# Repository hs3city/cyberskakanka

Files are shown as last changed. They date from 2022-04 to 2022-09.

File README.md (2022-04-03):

# cyberskakanka

## Wiring the Stuff Together

### Connecting Arduino and Weight Sensors

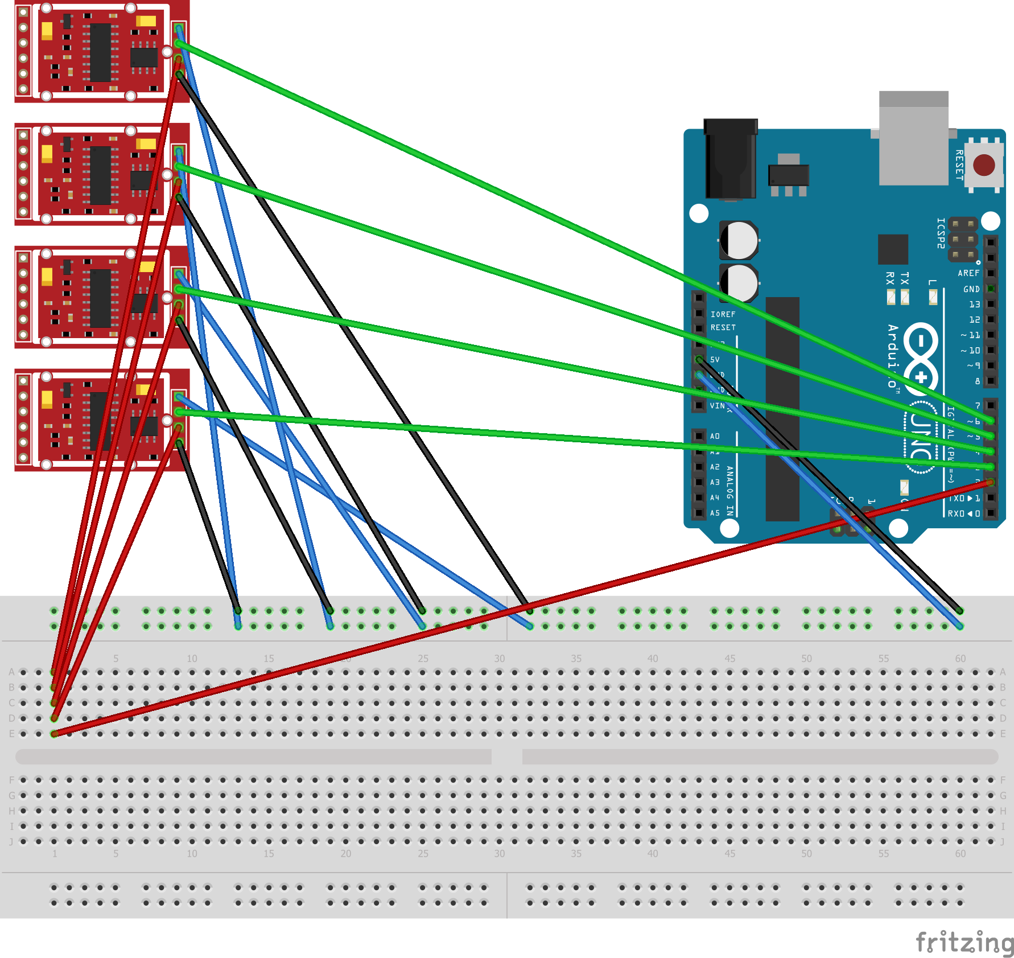
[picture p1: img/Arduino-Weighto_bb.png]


### Connecting Arduino and Raspberry Pi via I2C

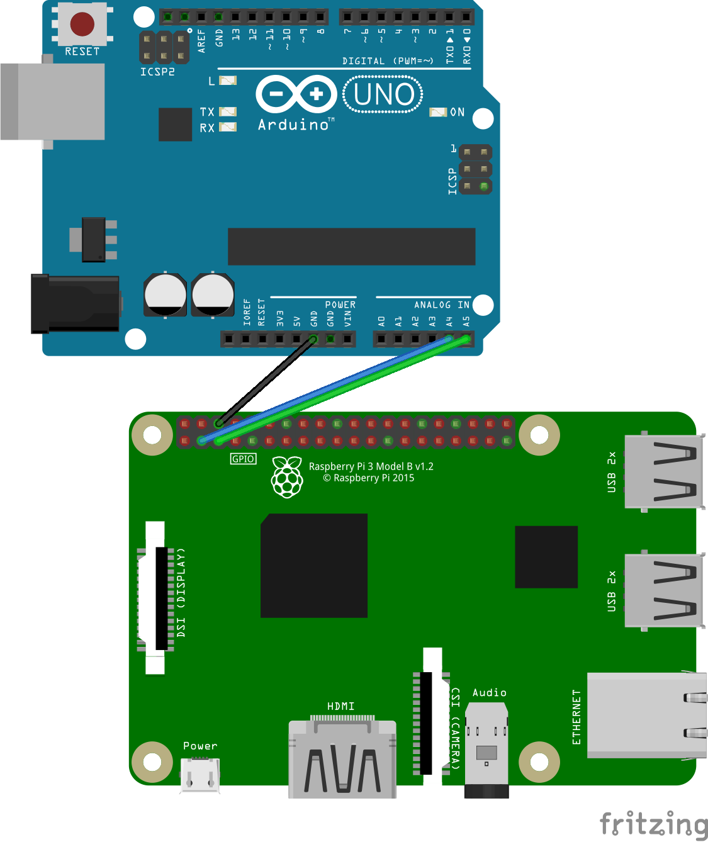
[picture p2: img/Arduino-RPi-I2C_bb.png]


### Connecting Raspberry Pi with WS212B LED Strip

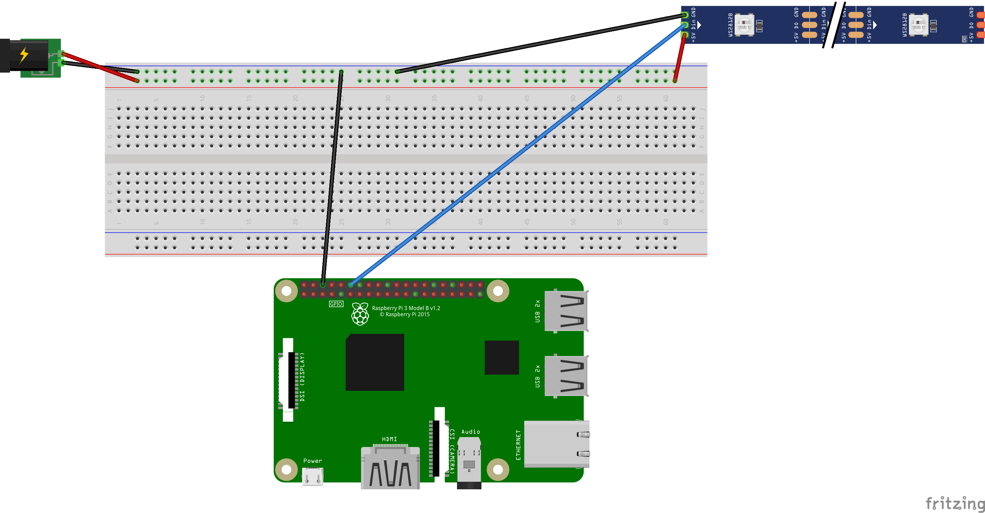
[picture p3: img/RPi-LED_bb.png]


## The Hardware

### The Base

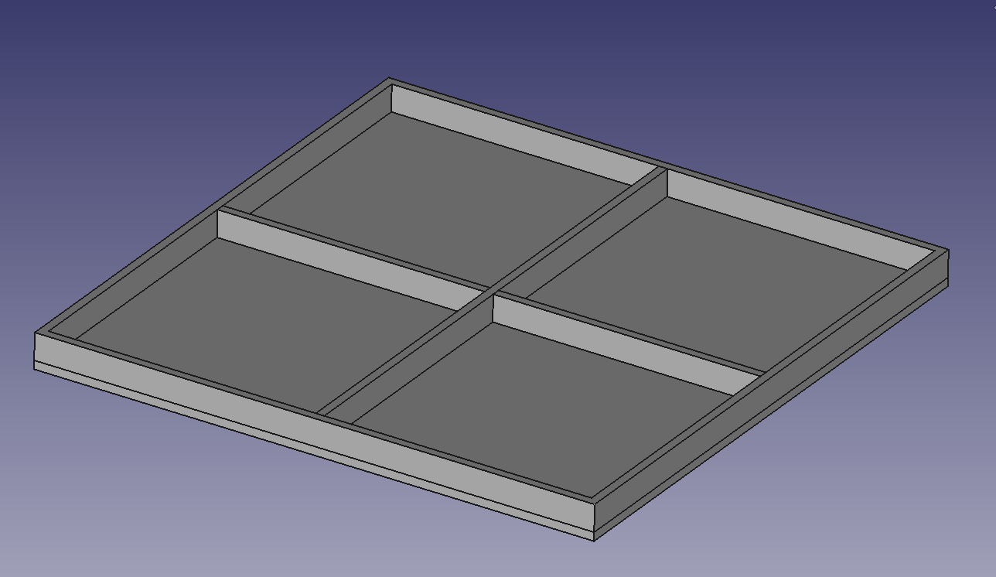
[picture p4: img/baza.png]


### The Base with Two Tiles Fit

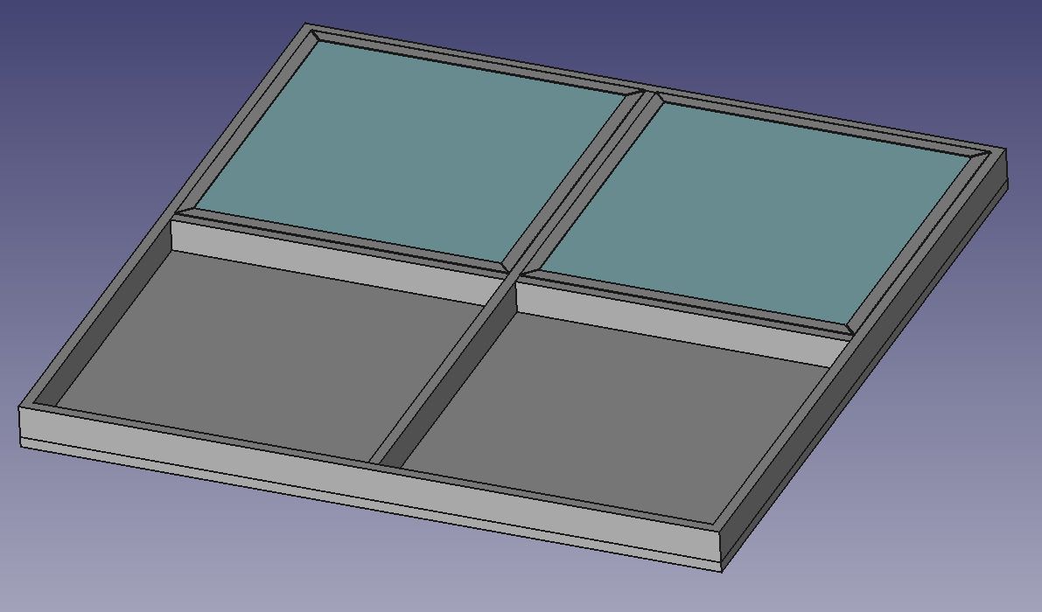
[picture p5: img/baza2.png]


### The Tile

- 16mm MDF on the bottom
- a layer of white cardboard
- 5mm transparent plexi

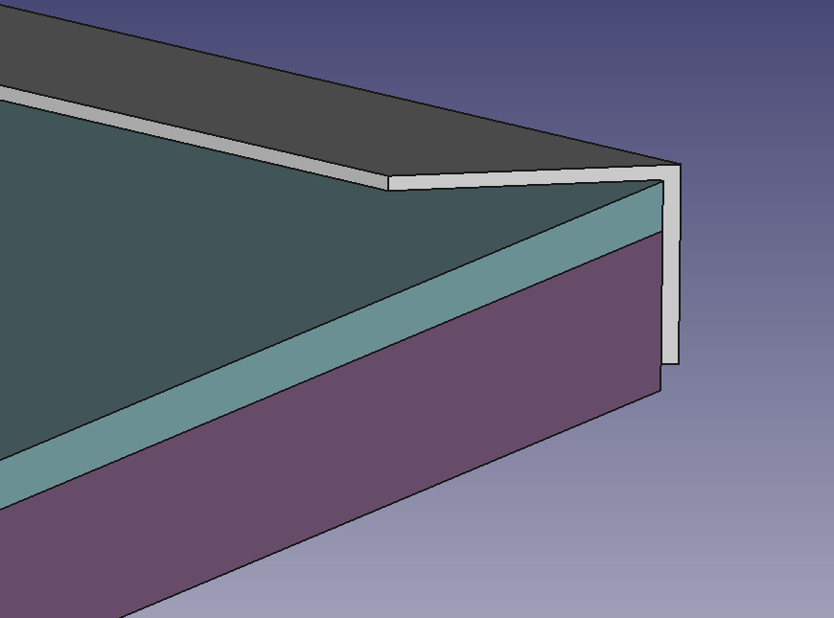
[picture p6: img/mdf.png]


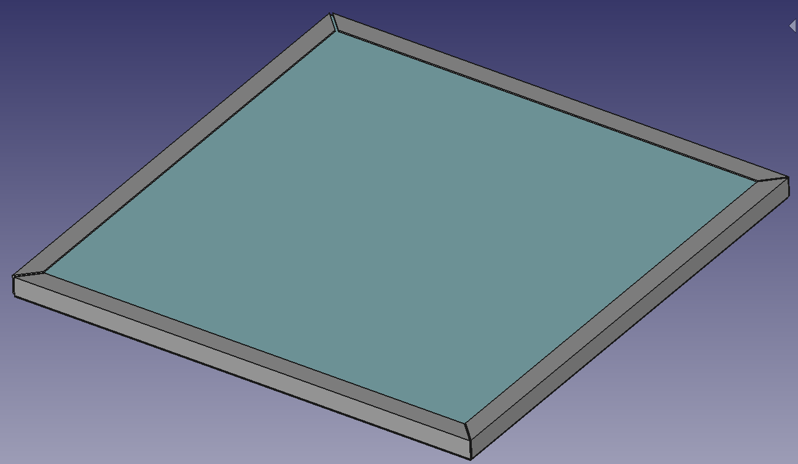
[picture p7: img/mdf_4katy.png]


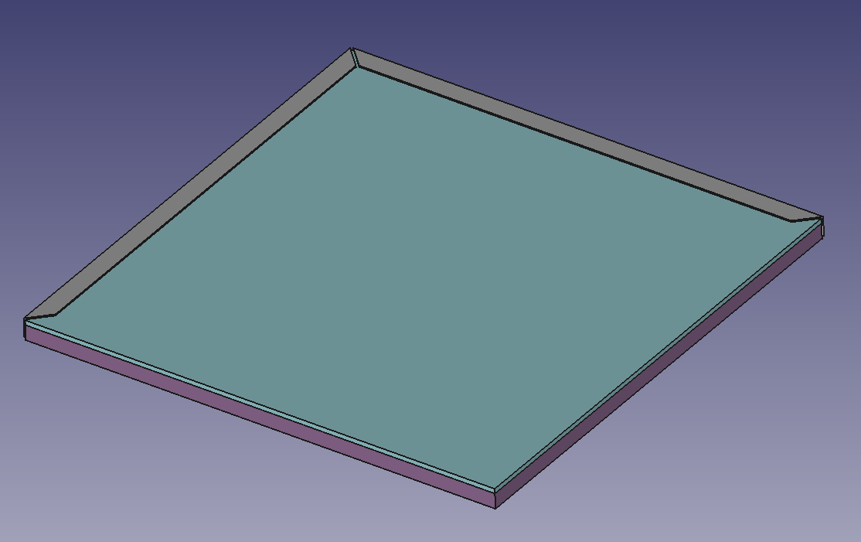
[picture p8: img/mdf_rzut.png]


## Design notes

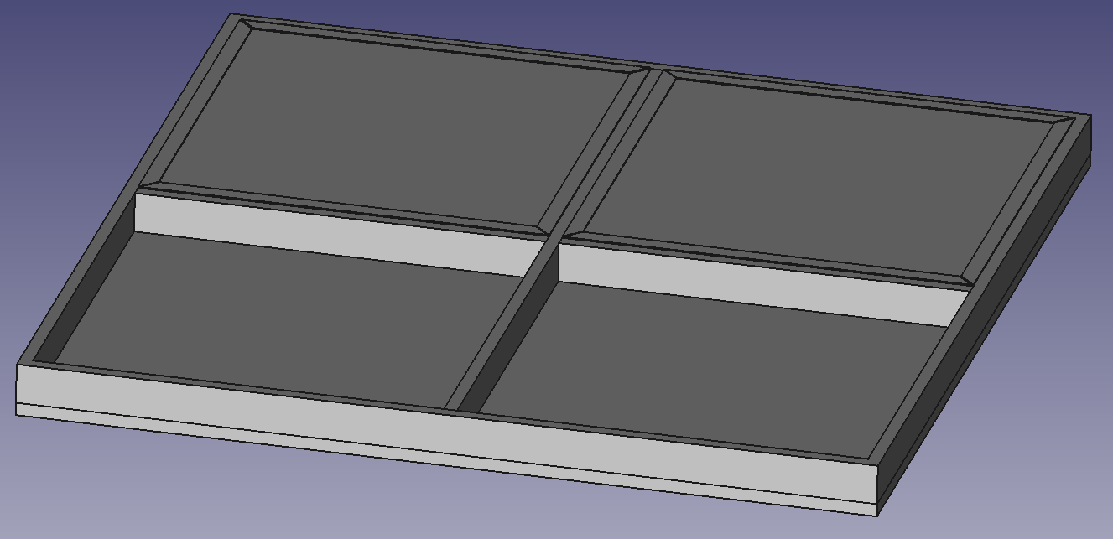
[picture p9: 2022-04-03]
img/cyberskakanka.png

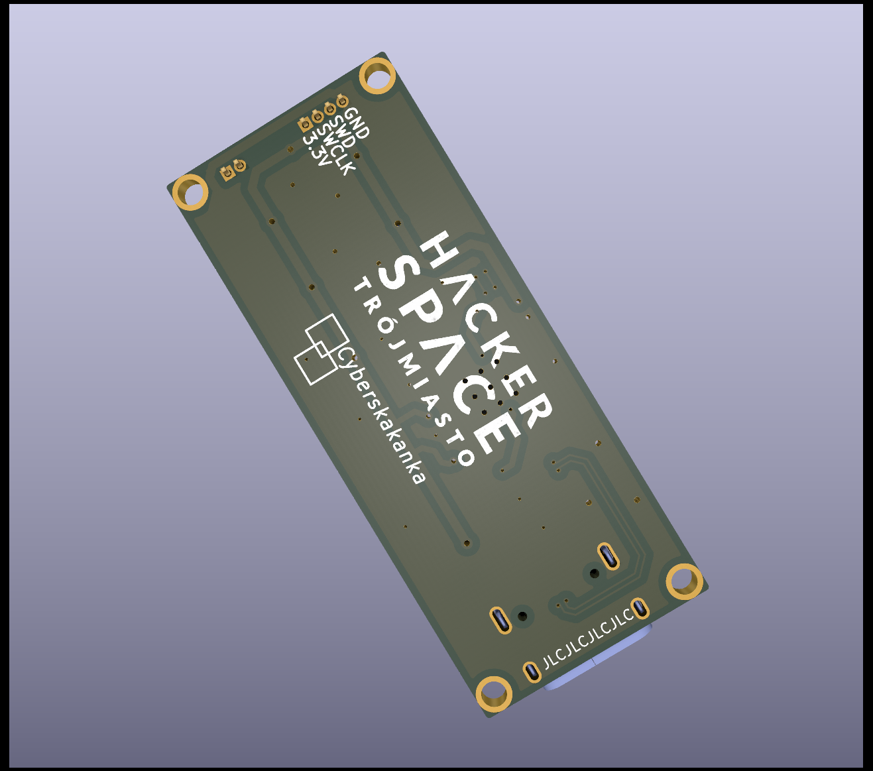
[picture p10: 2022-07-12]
hs3-arduino-nano/export/hs3-arduino-nano-bottom.png

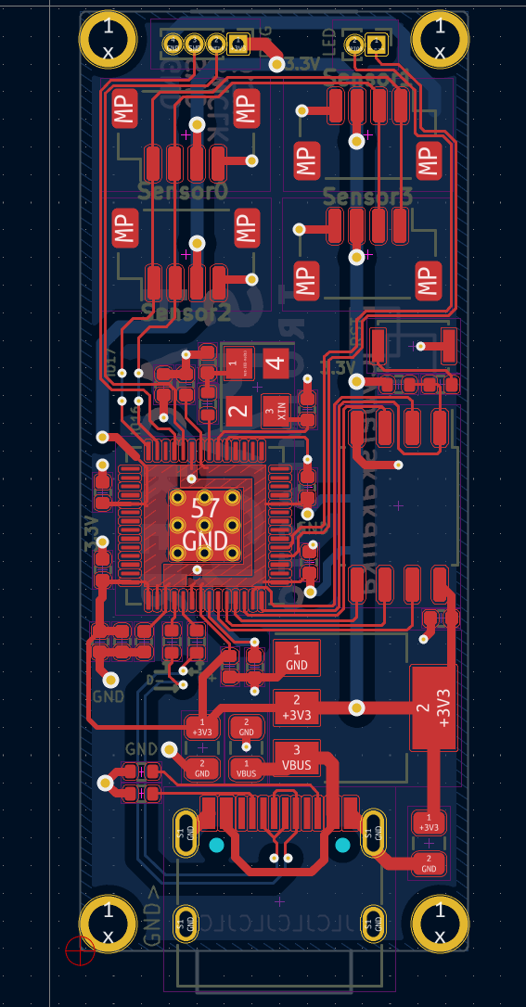
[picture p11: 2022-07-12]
hs3-arduino-nano/export/pcb.png

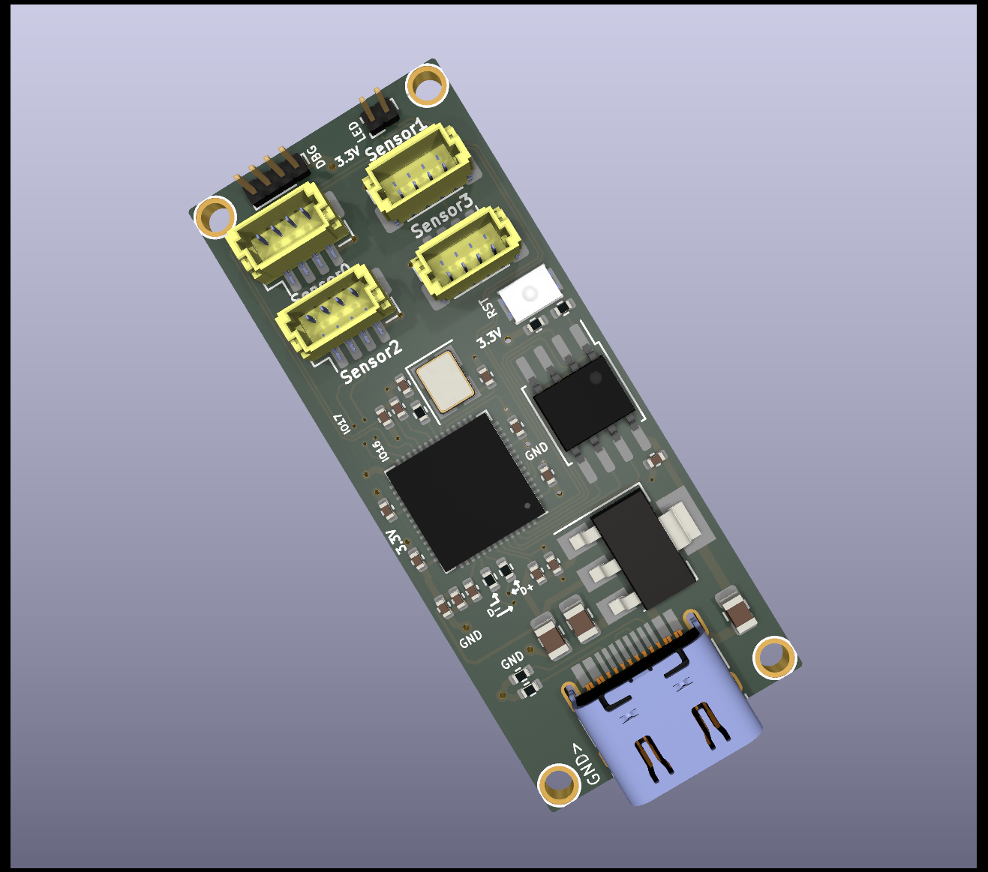
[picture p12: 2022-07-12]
hs3-arduino-nano/export/hs3-arduino-nano-top.png

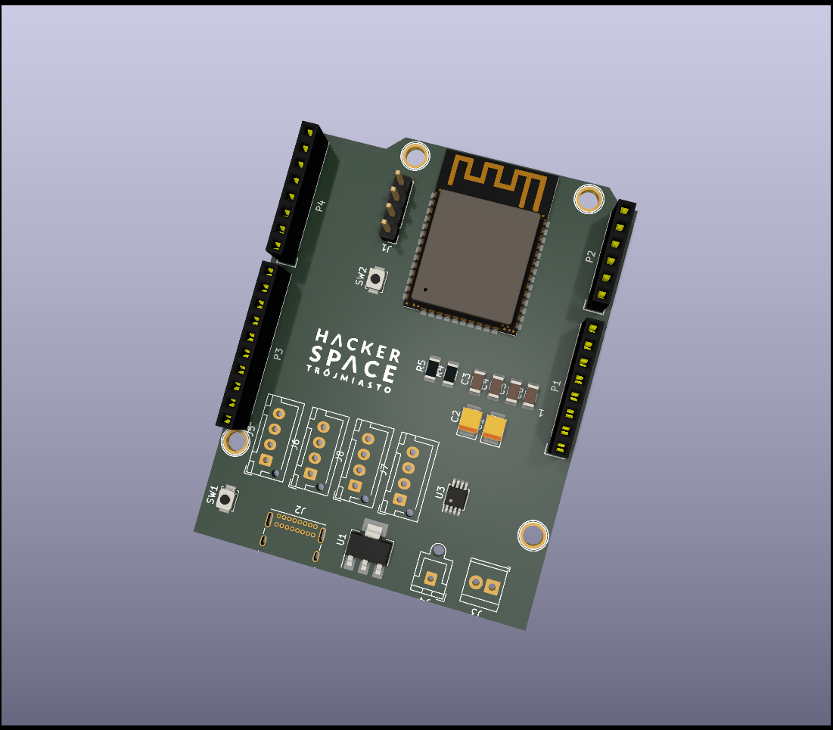
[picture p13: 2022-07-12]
hs3-arduino/hs3-arduino-render.png

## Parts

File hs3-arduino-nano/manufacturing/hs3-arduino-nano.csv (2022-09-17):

Comment | Designator | Footprint | LCSC
27p | C1,C2 | Capacitor_SMD:C_0402_1005Metric | C1557
10u | C3,C5,C6 | Capacitor_SMD:C_0805_2012Metric | C15850
100n | C4,C7,C8,C10,C12,C13,C14,C15,C16,C17 | Capacitor_SMD:C_0402_1005Metric | C307331
1u | C9,C11 | Capacitor_SMD:C_0402_1005Metric | C52923
USB_C_Receptacle_USB2.0 | J1 | Connector_USB:USB_C_Receptacle_HRO_TYPE-C-31-M-12
DBG | J3 | Connector_PinHeader_1.00mm:PinHeader_1x04_P1.00mm_Vertical
LED | J4 | Connector_PinHeader_1.00mm:PinHeader_1x02_P1.00mm_Vertical
CONN_01X01 | P3,P4,P5,P6 | Socket_Arduino_Nano:1pin_Nano
1k | R1 | Resistor_SMD:R_0402_1005Metric | C25905
0 | R5 | Resistor_SMD:R_0402_1005Metric | C17168
5.1k | R2,R4 | Resistor_SMD:R_0402_1005Metric | C25905
10k | R3 | Resistor_SMD:R_0402_1005Metric | C25744
27 | R6,R7 | Resistor_SMD:R_0402_1005Metric | 0402
Boot | SW1 | Button_Switch_SMD:SW_SPST_CK_KXT3 | C2689509
CONN_01x04 | Sensor0,Sensor1,Sensor2,Sensor3 | Connector_JST:JST_SH_BM04B-SRSS-TB_1x04-1MP_P1.00mm_Vertical
W25Q128JVS | U1 | Package_SO:SOIC-8_5.23x5.23mm_P1.27mm | C97521
NCP1117-3.3_SOT223 | U2 | Package_TO_SOT_SMD:SOT-223-3_TabPin2 | C6186
RP2040 | U3 | RP2040:RP2040-QFN-56 | C2040
OT201612MJBA4SL | XTAL1 | Crystal:Crystal_SMD_2016-4Pin_2.0x1.6mm | C669076

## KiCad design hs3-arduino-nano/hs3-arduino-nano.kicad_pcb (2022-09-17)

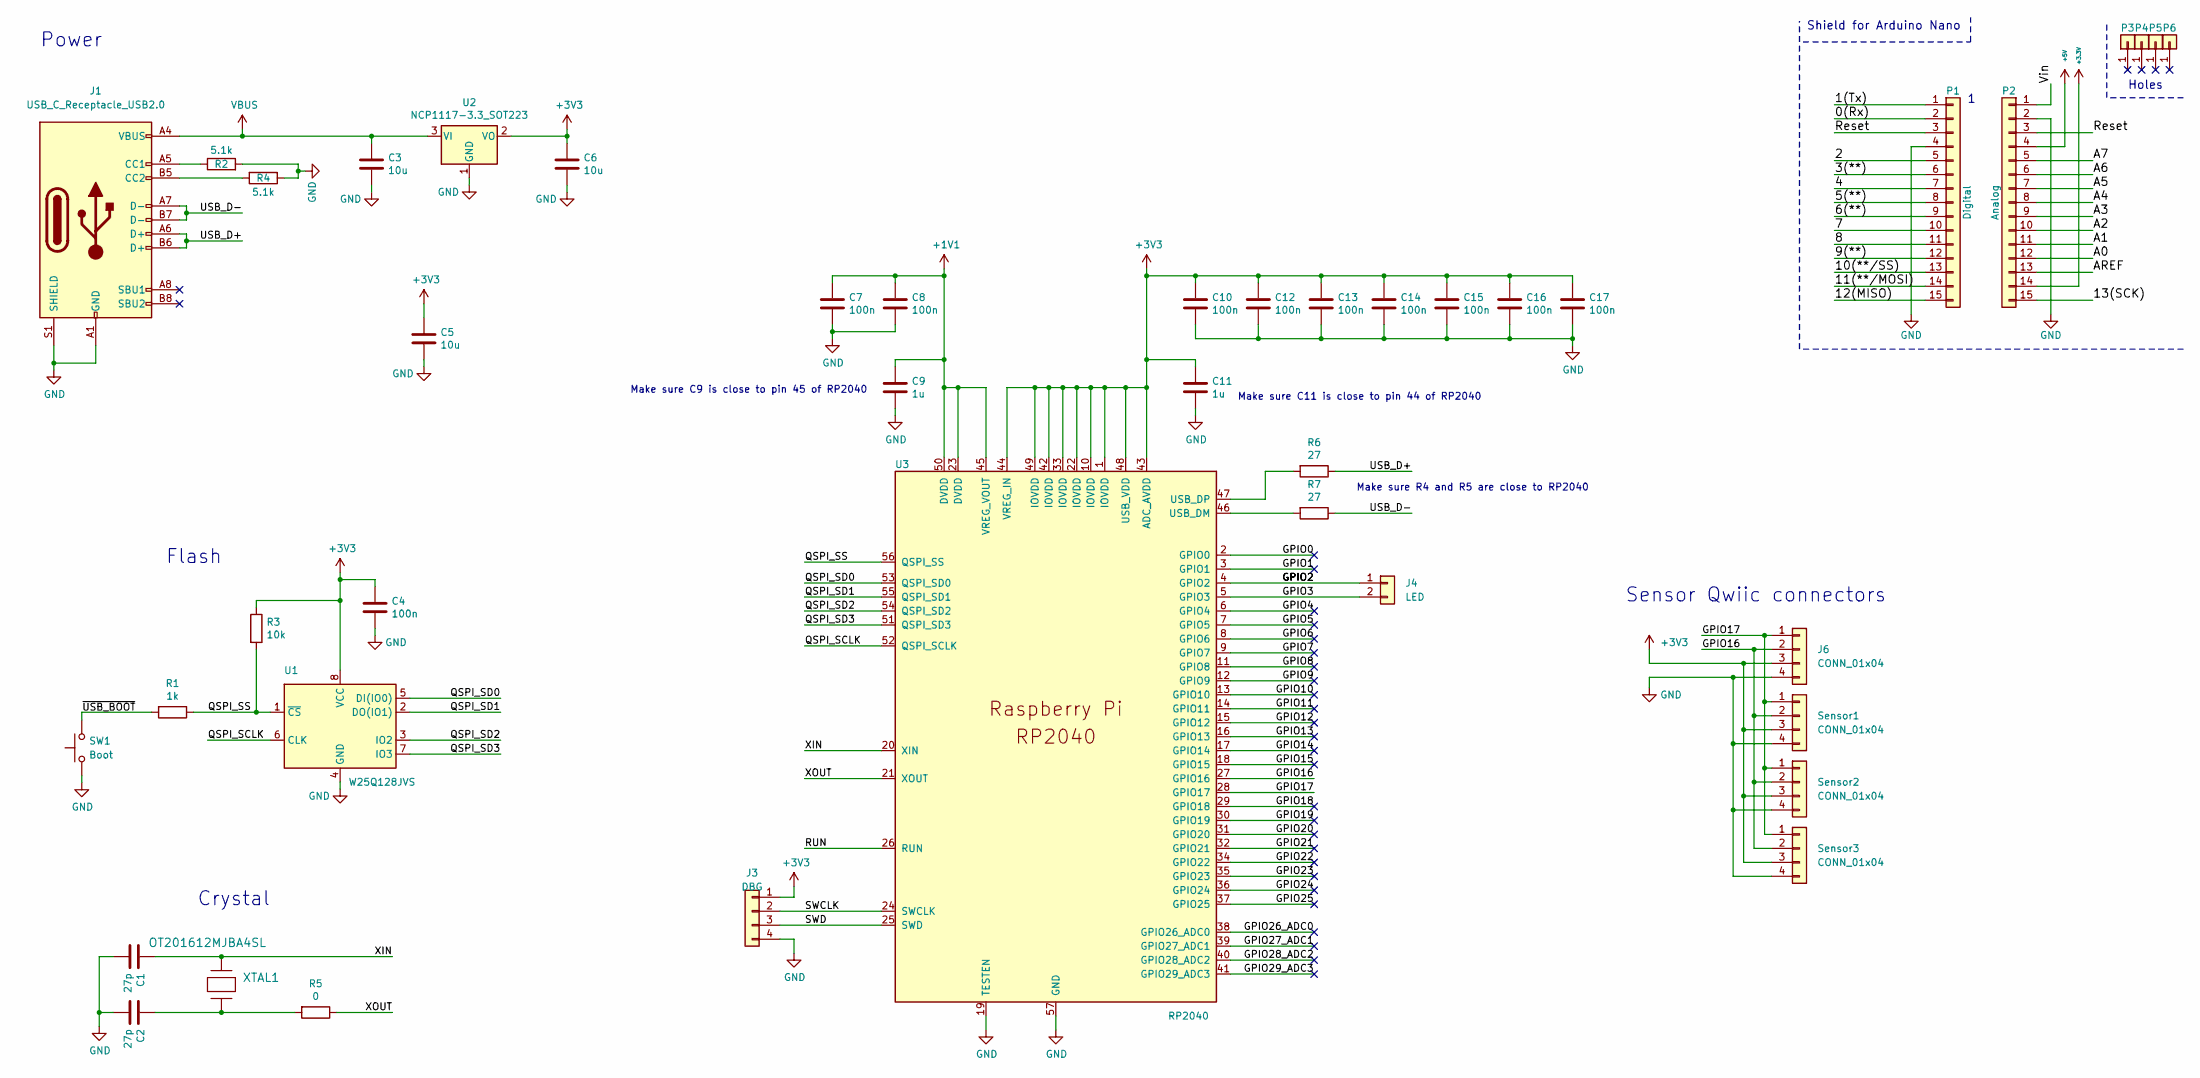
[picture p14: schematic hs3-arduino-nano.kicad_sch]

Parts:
C1, C2: 27p; C_0402_1005Metric; LCSC C1557
C3, C5, C6: 10u; C_0805_2012Metric; LCSC C15850
C4, C7, C8, C10, C12, C13, C14, C15, C16, C17: 100n; C_0402_1005Metric; LCSC C307331
C9, C11: 1u; C_0402_1005Metric; LCSC C52923
J1: USB_C_Receptacle_USB2.0; USB_C_Receptacle_HRO_TYPE-C-31-M-12
J3: DBG; PinHeader_1x04_P1.00mm_Vertical
J4: LED; PinHeader_1x02_P1.00mm_Vertical
J6: CONN_01x04; JST_SH_BM04B-SRSS-TB_1x04-1MP_P1.00mm_Vertical
P1: Digital; Socket_Strip_Arduino_1x15
P2: Analog; Socket_Strip_Arduino_1x15
P3, P4, P5, P6: CONN_01X01; 1pin_Nano
R1: 1k; R_0402_1005Metric; LCSC C25905
R2, R4: 5.1k; R_0402_1005Metric; LCSC C25905
R3: 10k; R_0402_1005Metric; LCSC C25744
R5: 0; R_0402_1005Metric; LCSC C17168
R6, R7: 27; R_0402_1005Metric; LCSC 0402
SW1: Boot; SW_SPST_CK_KXT3; LCSC C2689509
Sensor1, Sensor2, Sensor3: CONN_01x04; JST_SH_BM04B-SRSS-TB_1x04-1MP_P1.00mm_Vertical
U1: W25Q128JVS; SOIC-8_5.23x5.23mm_P1.27mm; LCSC C97521
U2: NCP1117-3.3_SOT223; SOT-223-3_TabPin2; LCSC C6186
U3: RP2040; RP2040-QFN-56; LCSC C2040
XTAL1: OT201612MJBA4SL; Crystal_SMD_2016-4Pin_2.0x1.6mm; LCSC C669076

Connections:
+1V1: C7.1, C8.1, C9.1, U3.23 (DVDD), U3.45 (VREG_VOUT), U3.50 (DVDD)
+3V3: C4.1, C5.1, C6.1, C10.1, C11.1, C12.1, C13.1, C14.1, C15.1, C16.1, C17.1, J3.1, J6.3, R3.1, Sensor1.3, Sensor2.3, Sensor3.3, U1.8 (VCC), U2.2 (VO), U3.1 (IOVDD), U3.10 (IOVDD), U3.22 (IOVDD), U3.33 (IOVDD), U3.42 (IOVDD), U3.43 (ADC_AVDD), U3.44 (VREG_IN), U3.48 (USB_VDD), U3.49 (IOVDD)
/GPIO0: U3.2 (GPIO0)
/GPIO1: U3.3 (GPIO1)
/GPIO3: J4.2, U3.5 (GPIO3)
/GPIO4: U3.6 (GPIO4)
/GPIO5: U3.7 (GPIO5)
/GPIO6: U3.8 (GPIO6)
/GPIO7: U3.9 (GPIO7)
/GPIO8: U3.11 (GPIO8)
/GPIO9: U3.12 (GPIO9)
/GPIO10: U3.13 (GPIO10)
/GPIO11: U3.14 (GPIO11)
/GPIO12: U3.15 (GPIO12)
/GPIO13: U3.16 (GPIO13)
/GPIO14: U3.17 (GPIO14)
/GPIO15: U3.18 (GPIO15)
/GPIO16: J6.2, Sensor1.2, Sensor2.2, Sensor3.2, U3.27 (GPIO16)
/GPIO17: J6.1, Sensor1.1, Sensor2.1, Sensor3.1, U3.28 (GPIO17)
/GPIO18: U3.29 (GPIO18)
/GPIO19: U3.30 (GPIO19)
/GPIO20: U3.31 (GPIO20)
/GPIO21: U3.32 (GPIO21)
/GPIO22: U3.34 (GPIO22)
/GPIO23: U3.35 (GPIO23)
/GPIO24: U3.36 (GPIO24)
/GPIO25: U3.37 (GPIO25)
/GPIO26_ADC0: U3.38 (GPIO26_ADC0)
/GPIO27_ADC1: U3.39 (GPIO27_ADC1)
/GPIO28_ADC2: U3.40 (GPIO28_ADC2)
/GPIO29_ADC3: U3.41 (GPIO29_ADC3)
/QSPI_SCLK: U1.6 (CLK), U3.52 (QSPI_SCLK)
/QSPI_SD0: U1.5 (DI(IO0)), U3.53 (QSPI_SD0)
/QSPI_SD1: U1.2 (DO(IO1)), U3.55 (QSPI_SD1)
/QSPI_SD2: U1.3 (IO2), U3.54 (QSPI_SD2)
/QSPI_SD3: U1.7 (IO3), U3.51 (QSPI_SD3)
/QSPI_SS: R1.1, R3.2, U1.1 (~CS), U3.56 (QSPI_SS)
/RUN: U3.26 (RUN)
/SWCLK: J3.2, U3.24 (SWCLK)
/SWD: J3.3, U3.25 (SWD)
/USB_D+: J1.A6 (D+), J1.B6 (D+), R6.1
/USB_D-: J1.A7 (D-), J1.B7 (D-), R7.1
/XIN: C1.1, U3.20 (XIN), XTAL1.3
/XOUT: R5.1, U3.21 (XOUT)
/~USB_BOOT: R1.2, SW1.2
GND: C1.2, C2.2, C3.2, C4.2, C5.2, C6.2, C7.2, C8.2, C9.2, C10.2, C11.2, C12.2, C13.2, C14.2, C15.2, C16.2, C17.2, J1.A1 (GND), J1.A12 (GND), J1.B1 (GND), J1.B12 (GND), J1.S1 (SHIELD), J3.4, J6.4, P1.4, P2.2, R2.2, R4.1, SW1.1, Sensor1.4, Sensor2.4, Sensor3.4, U1.4 (GND), U2.1 (GND), U3.19 (TESTEN), U3.57 (GND)
unnamed: C2.1, R5.2, XTAL1.1
unnamed: J1.A5 (CC1), R2.1
unnamed: J1.B5 (CC2), R4.2
unnamed: J4.1, U3.4 (GPIO2)
unnamed: P1.3, P2.3
unnamed: R6.2, U3.47 (USB_DP)
unnamed: R7.2, U3.46 (USB_DM)
VBUS: C3.1, J1.A4 (VBUS), J1.A9 (VBUS), J1.B4 (VBUS), J1.B9 (VBUS), U2.3 (VI)

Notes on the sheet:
Flash
Holes
Make sure C9 is close to pin 45 of RP2040
Shield for Arduino Nano
Make sure R4 and R5 are close to RP2040
Power
Make sure C11 is close to pin 44 of RP2040
Sensor Qwiic connectors
Crystal

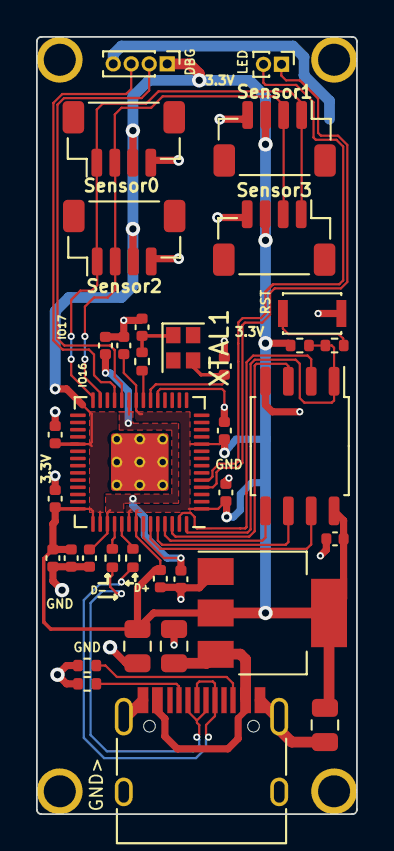
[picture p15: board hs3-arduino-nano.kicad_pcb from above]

Board: 2 copper layers, 17.8 x 43.2 mm, 41 parts (0 on the bottom side), 26 nets.

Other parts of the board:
G2: LOGO

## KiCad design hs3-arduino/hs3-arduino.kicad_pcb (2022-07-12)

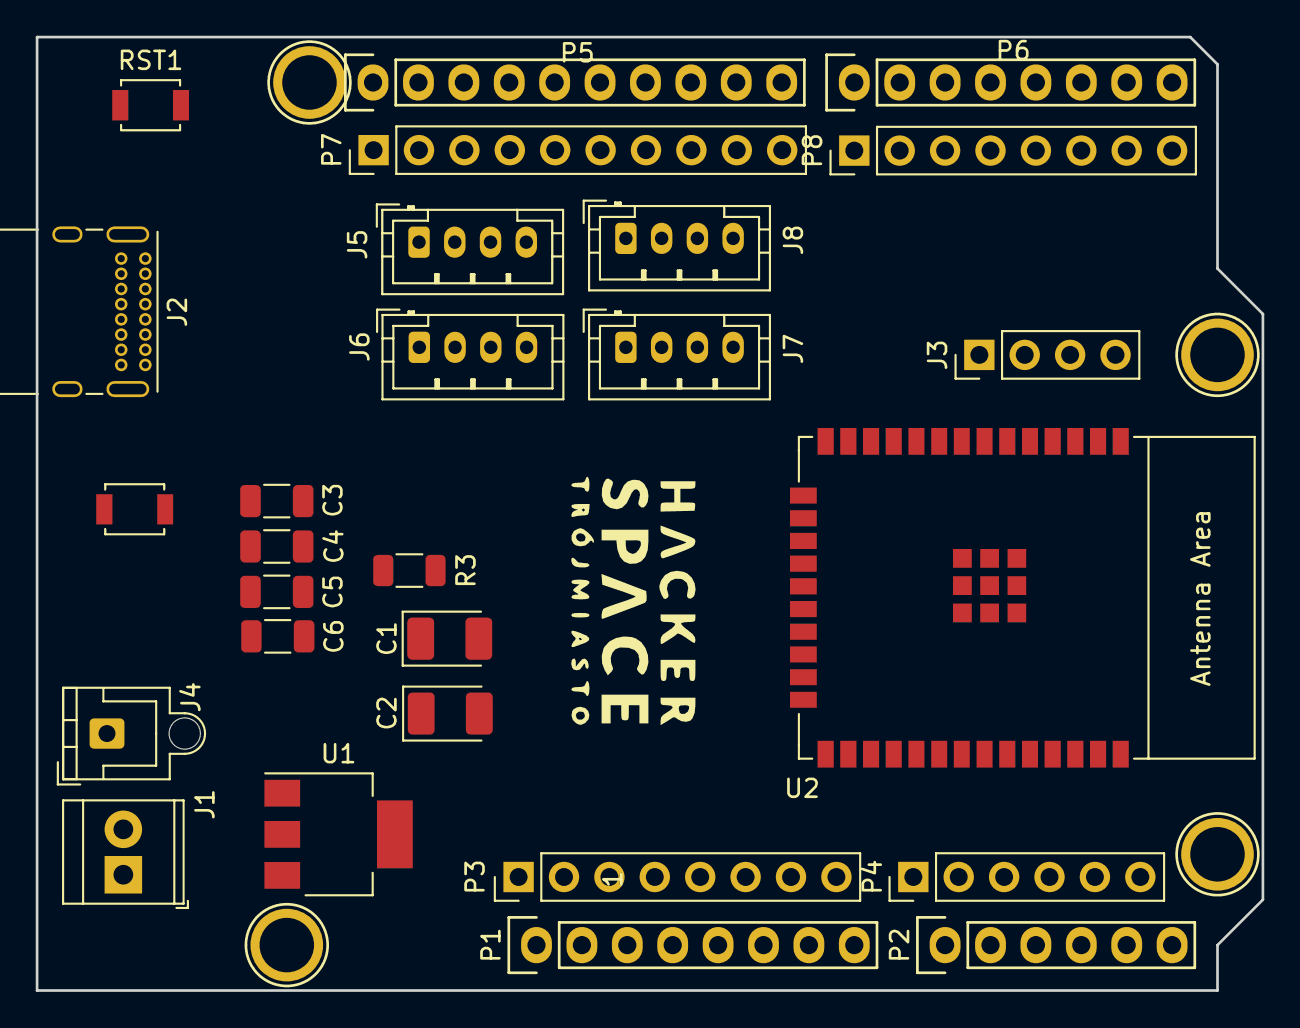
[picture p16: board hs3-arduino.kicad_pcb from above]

Board: 2 copper layers, 68.6 x 53.3 mm, 31 parts (0 on the bottom side), 28 nets, no tracks yet.

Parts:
BOOT1: Boot Option; SW_SPST_B3U-1000P
C1, C2: 22uF; CP_EIA-3528-12_Kemet-T_Pad1.50x2.35mm_HandSolder
C3: 10u; C_1206_3216Metric
C4, C5, C6: 100nF; C_1206_3216Metric
J1: Conn_01x02; TerminalBlock_TE_282834-2_1x02_P2.54mm_Horizontal
J2: USB_C_Receptacle_USB2.0; USB_C_Receptacle_GCT_USB4085
J3: Serial; PinHeader_1x04_P2.54mm_Vertical
J4: LED Data; JST_XH_B1B-XH-AM_1x01_P2.50mm_Vertical
J5, J6, J7, J8: I2C Header; JST_PH_B4B-PH-K_1x04_P2.00mm_Vertical
P1: Power; Socket_Strip_Arduino_1x08
P2: Analog; Socket_Strip_Arduino_1x06
P3: Power; PinHeader_1x08_P2.54mm_Vertical
P4: Analog; PinHeader_1x06_P2.54mm_Vertical
P5: Digital; Socket_Strip_Arduino_1x10
P6: Digital; Socket_Strip_Arduino_1x08
P7: Digital; PinHeader_1x10_P2.54mm_Vertical
P8: Digital; PinHeader_1x08_P2.54mm_Vertical
P9, P10, P11, P12: CONN_01X01; Arduino_1pin
R3: 10k; R_1206_3216Metric
RST1: Reset; SW_SPST_B3U-1000P
U1: AMS1117-3.3; SOT-223-3_TabPin2
U2: ESP32-WROOM-32E

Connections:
+3V3: C2.1, C3.1, C4.1, J3.1, J5.1, J6.1, J7.1, J8.1, P1.4, P3.4, R3.1, U1.2 (VO), U2.2 (3V3)
+5V: C1.1, J1.1, P1.5, P1.8, P3.5, P3.8, U1.3 (VI)
/0(Rx): J3.3, P6.8, P8.8, U2.34 (U0RXD/GPIO3)
/1(Tx): J3.2, P6.7, P8.7, U2.35 (U0TXD/GPIO1)
/2: P6.6, P8.6, U2.24 (ADC2_CH2/GPIO2)
/3(**): P6.5, P8.5, U2.26 (ADC2_CH0/GPIO4)
/4: P6.4, P8.4, U2.29 (GPIO5)
/5(**): P6.3, P8.3, U2.27 (GPIO16)
/6(**): P6.2, P8.2, U2.28 (GPIO17)
/7: P6.1, P8.1, U2.30 (GPIO18)
/8: P5.10, P7.10, U2.31 (GPIO19)
/9(**): P5.9, P7.9, U2.33 (GPIO21)
/10(**/SS): P5.8, P7.8, U2.36 (GPIO22)
/11(**/MOSI): P5.7, P7.7, U2.37 (GPIO23)
/12(MISO): P5.6, P7.6, U2.10 (DAC_1/ADC2_CH8/GPIO25)
/13(SCK): P5.5, P7.5, U2.11 (DAC_2/ADC2_CH9/GPIO26)
/A0: P2.1, P4.1, U2.6 (GPIO34/ADC1_CH6)
/A1: P2.2, P4.2, U2.7 (GPIO35/ADC1_CH7)
/A2: P2.3, P4.3, U2.4 (SENSOR_VP/GPIO36/ADC1_CH0)
/A3: P2.4, P4.4, U2.5 (SENSOR_VN/GPIO39/ADC1_CH3)
/A4(SDA): J5.4, J6.4, J7.4, J8.4, P2.5, P4.5, P5.2, P7.2, U2.13 (MTMS/GPIO14/ADC2_CH6)
/A5(SCL): J5.3, J6.3, J7.3, J8.3, P2.6, P4.6, P5.1, P7.1, U2.23 (MTDO/GPIO15/ADC2_CH3)
/AREF: P5.3, P7.3
/Bootsel: BOOT1.2, U2.25 (GPIO0/BOOT/ADC2_CH1)
/IOREF: P1.2, P3.2
/LED Data: J4.1, U2.12 (ADC2_CH7/GPIO27)
/Reset: C5.1, C6.1, P1.3, R3.2, RST1.2, U2.3 (EN/CHIP_PU)
GND: BOOT1.1, C1.2, C2.2, C3.2, C4.2, C5.2, C6.2, J1.2, J3.4, J5.2, J6.2, J7.2, J8.2, P1.6, P1.7, P3.6, P3.7, P5.4, P7.4, RST1.1, U1.1 (GND), U2.1 (GND), U2.15 (GND), U2.38 (GND)

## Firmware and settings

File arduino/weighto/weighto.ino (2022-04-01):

#include <HX711.h>
#include <Wire.h>

#define calibrationFactor -3050.0 // This value is obtained using the SparkFun_HX711_Calibration sketch
#define NUMBER_OF_WEIGHTS 4

#define I2C_ADDRESS       0x10

#define weightSensorPinsStart 3
#define weightSensorClock  2

#define weightThreshold   30

HX711 weightSensor[NUMBER_OF_WEIGHTS];

float values[NUMBER_OF_WEIGHTS];

void setup() {
  Wire.begin(I2C_ADDRESS);

  Wire.onRequest(requestEvent);

  Serial.begin(9600);
  Serial.println("Cyber!123");

  initWeight();
}

void initWeight() {
  for (int i = 0; i < NUMBER_OF_WEIGHTS; i++) {
    weightSensor[i].begin(weightSensorPinsStart + i, weightSensorClock);
    weightSensor[i].set_scale(calibrationFactor); //This value is obtained by using the SparkFun_HX711_Calibration sketch
    weightSensor[i].tare(); //Assuming there is no weight on the scale at start up, reset the scale to 0
  }
}

void requestEvent() {
  Wire.write((uint8_t*)values, NUMBER_OF_WEIGHTS * sizeof(values[0]));
}

void loop() {
  for (int i = 0; i < NUMBER_OF_WEIGHTS; i++) {
    values[i] = (weightSensor[i].get_units(3));
  }
  delay(8);
}

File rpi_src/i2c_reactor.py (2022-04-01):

#  Raspberry Pi Master for Arduino Slave
#  i2c_master_pi.py
#  Connects to Arduino via I2C
  
#  DroneBot Workshop 2019
#  https://dronebotworkshop.com

from smbus2 import SMBus
import math
import struct
import time
import board
import neopixel

led_per_square = 30

pixels = neopixel.NeoPixel(board.D18, 10 * led_per_square, auto_write=False, pixel_order=neopixel.GRB)

bus = SMBus(1) # indicates /dev/ic2-1
addrs = board.I2C().scan()

weight_threshold = 30

def clear_led():
    pixels.fill((0,0,0))
    pixels.show()

def set_led(index, color):
    for i in range(index * led_per_square, (index+1) * led_per_square):
        pixels[i] = color

def main():
    clear_led()
    while True:
        time.sleep(0.1)

        for addr in addrs:
            v = bus.read_i2c_block_data(addr, 0, 16)
            v = struct.unpack('ffff', bytearray(v))
            print(addr, v)
            for i in range(len(v)):
                if not math.isnan(v[i]):
                    if v[i] > 2 * weight_threshold:
                        set_led(i, (0, 255, 0))
                    elif v[i] > weight_threshold:
                        set_led(i, (255, 0, 0))
                    else:
                        set_led(i, (0, 0, 0))
            pixels.show()

if __name__ == '__main__':
    main()

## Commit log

2022-04-01 Add some docs
    [Arduino-RPi-I2C.fzz, Arduino-Weighto.fzz, RPi-LED.fzz]
2022-04-03 Add CAD renderings
2022-06-09 Adding duplicated Arduino pins
    [hs3-arduino.kicad_pcb, hs3-arduino.kicad_sch]
2022-06-13 Initial commit for Nano version of hs3-arduino
    [hs3-arduino-nano.kicad_pcb, hs3-arduino-nano.kicad_sch]
2022-06-13 Minor cleanup in element placement
    [hs3-arduino-nano.kicad_pcb]
2022-06-24 First stab at routing
    [hs3-arduino-nano.kicad_pcb, hs3-arduino-nano.kicad_sch]
2022-06-25 Redone placement, new routing
    [hs3-arduino-nano.kicad_pcb, hs3-arduino-nano.kicad_sch]
2022-06-26 Minor fixes to labels on silkscreen
    [hs3-arduino-nano.kicad_pcb]
2022-06-26 Post-review place & route update pt. 1
    [hs3-arduino-nano.kicad_pcb]
2022-06-27 Post-review place & route update pt. 2
    [hs3-arduino-nano.kicad_pcb, hs3-arduino-nano.kicad_sch]
2022-06-28 Adding KiCAD template to .gitignore
2022-06-28 Shortening traces around 3.3V pins
    [hs3-arduino-nano.kicad_pcb]
2022-06-29 Minor cleanup in PCB, adding part numbers to BOM
    [hs3-arduino-nano.kicad_pcb, hs3-arduino-nano.kicad_sch]
2022-07-02 Adding manufacturing files
    [hs3-arduino-nano-B_Cu.gbl, hs3-arduino-nano-B_Mask.gbs, hs3-arduino-nano-B_Paste.gbp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]
2022-07-14 Fixing footprint for xtal
    [hs3-arduino-nano-B_Cu.gbl, hs3-arduino-nano-B_Mask.gbs, hs3-arduino-nano-B_Paste.gbp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]
2022-09-16 Fixing incorrect XTAL1 part number
    [hs3-arduino-nano.csv, hs3-arduino-nano.kicad_pcb, hs3-arduino-nano.kicad_sch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]
